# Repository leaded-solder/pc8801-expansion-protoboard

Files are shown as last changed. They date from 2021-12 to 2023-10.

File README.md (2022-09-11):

# NEC PC-8801 expansion protoboard
This board is meant to be a prototyping board for creating expansion cards for the NEC PC-8801 series of Japanese-market personal computers. It is intended to be a substitute for the Sunhayato MCC-151 prototyping board, which is (as far as I know) no longer available for purchase.

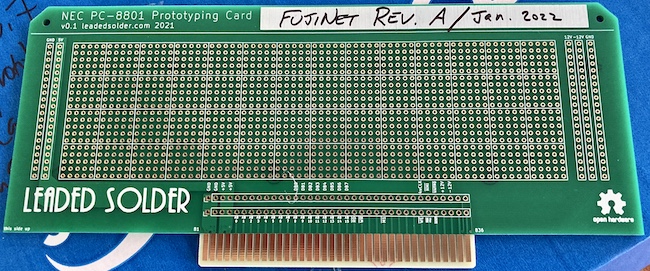
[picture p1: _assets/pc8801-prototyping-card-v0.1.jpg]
An unpopulated v0.1 card with ENIG gold edge fingers


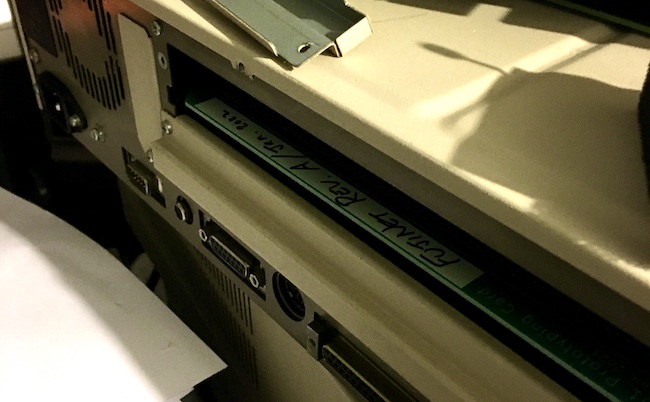
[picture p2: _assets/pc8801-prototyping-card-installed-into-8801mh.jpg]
The card installed into a PC-8801MH


This board was developed as part of a [leaded solder](https://www.leadedsolder.com) web log entry. If it saved you some time or money, [please consider backing the site on Patreon](https://www.patreon.com/leadedsolder).

## Bill of Materials (Optional)
The card itself is enough for most users, but you may wish to add a card ejector in order to make it easier to insert and remove the card while you are prototyping your circuit. The 8801 _really_ gets a death grip on those cards.

I have tested fitment with the common and still-available Bivar CP-26 series ejector, so I suggest buying that. Installing the roll pins for the ejector lever is somewhat challenging for me, so I would appreciate any advice on how to make it faster and more consistent!

## Version History
### v0.3
 - Fixed the problem with the PC-8801 edge footprint where the "B" side pins were on the bottom ("A" side) and the "A" side pins were on the top ("B" side.) As you might expect, this kept things from working!

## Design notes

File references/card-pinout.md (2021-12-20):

# Expansion card pinout for PC-8801
Based on [this page by youkan](http://www.maroon.dti.ne.jp/youkan/pc88/expslot.html)

| Side A (solder side) | I/O | Pin Number | I/O | Side B (part side) |
|---|-----|---|-----|---|
| GND | - | 1 | - | GND |
| GND | - | 2 | - | GND |
| +5V | - | 3 | - | +5V |
| +5V | - | 4 | - | +5V |
| AB0 | O | 5 | - | ~EXTRXRDY |
| AB1 | O | 6 | - | N/C |
| AB2 | O | 7 | I | ~MWAIT[^mwait] |
| AB3 | O | 8 | I | ~INT4 |
| AB4 | O | 9 | I | ~INT3 |
| AB5 | O | 10 | I | ~INT2 |
| AB6 | O | 11 | I | ~FDINT1 |
| AB7 | O | 12 | I | ~FDINT2 |
| AB8 | O | 13 | O | DB0 |
| AB9 | O | 14 | O | DB1 |
| AB10 | O | 15 | O | DB2 |
| AB11 | O | 16 | O | DB3 |
| AB12 | O | 17 | O | DB4 |
| AB13 | O | 18 | O | DB5 |
| AB14 | O | 19 | O | DB6 |
| AB15 | O | 20 | O | DB7 |
| ~RD | O | 21 | O | ~MEMR |
| ~WR | O | 22 | O | HIGH[^high] |
| ~MREQ | O | 23 | O | ~IOW |
| ~IORQ | O | 24 | O | ~IOR |
| ~M1 | O | 25 | O | ~MEMW |
| ~RAS0 | O | 26 | ??  | ~DMATC |
| ~RAS1 | O | 27 | ?? | DMRDY |
| ~RFSH | O | 28 | O | ~DRQ1,2 |
| ~MUX | O | 29 | O | ~DACK1,2 |
| ~WE | O | 30 | O  | 4xCLK[^4clk] |
| ~ROMKILL[^romkill] | I | 31 | I  | ~NMI |
| ~RESET | O | 32 | I  | ~WAITRQ |
| SCLK[^sclk] | O | 33 | -  | +12V |
| CLK[^clk] | O | 34 | -  | -12V |
| V1 | ?? | 35 | ??  | V1 |
| V2 | ?? | 36 | ??  | V2 |

[^high]: Pull-up to +5V
[^romkill]: Prevents computer from accessing built-in ROMs in $0000-7fff
[^mwait]: Adds one wait to the memory access (changes from setting the wait state DIP on the front of the computer)
[^4clk]: 4x CPU clock, AKA 15.9744MHz
[^sclk]: 76.8kHz?
[^clk]: 3.9936MHz

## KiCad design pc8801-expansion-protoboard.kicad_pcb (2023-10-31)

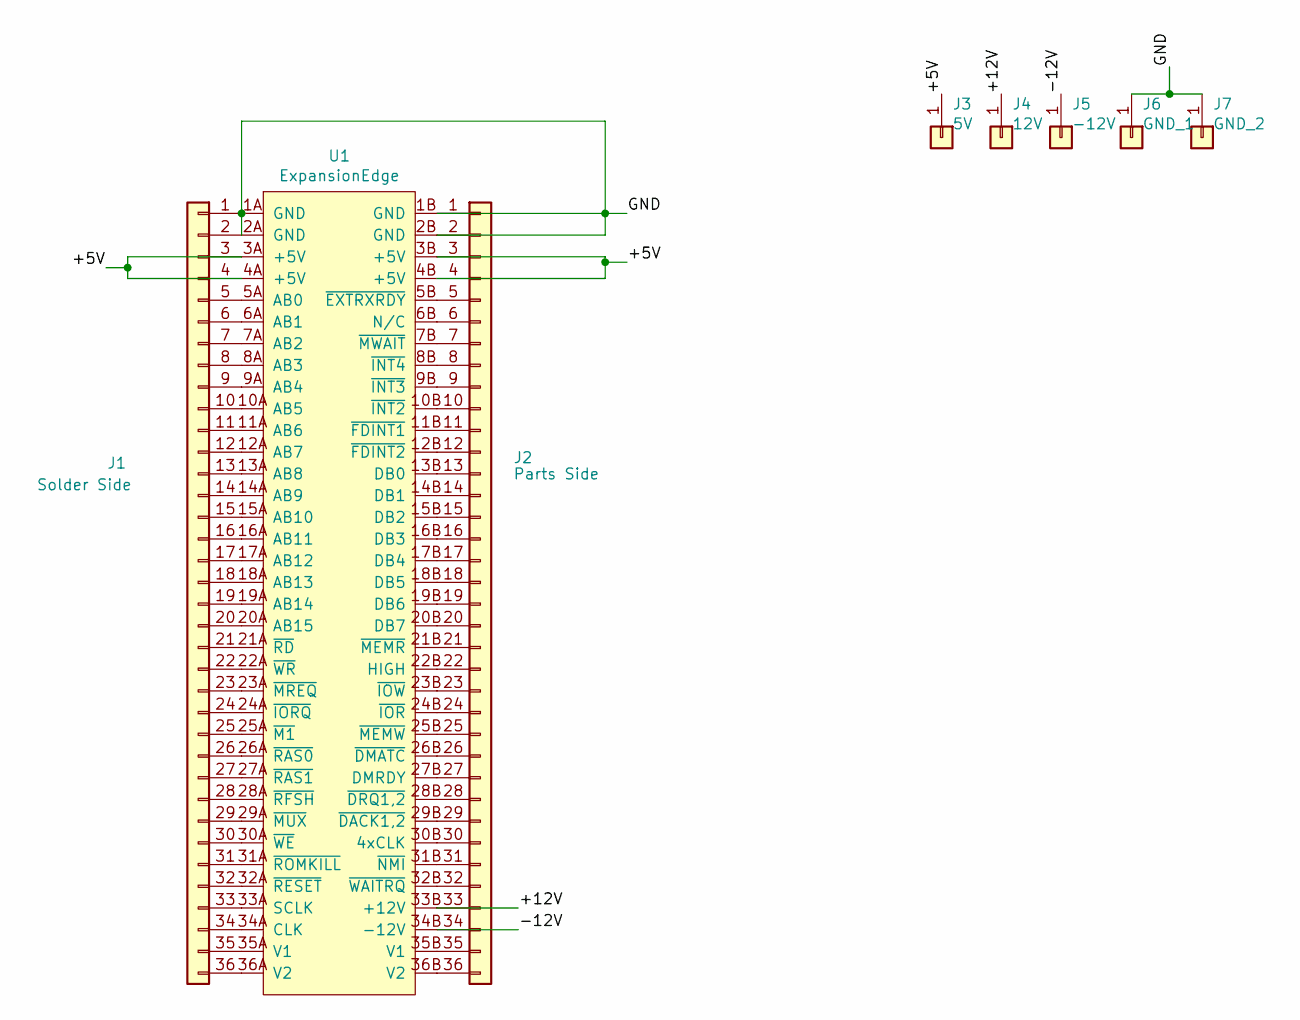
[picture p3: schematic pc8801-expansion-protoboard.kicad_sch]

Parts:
J1: Solder Side; PinHeader_1x36_P2.54mm_Vertical
J2: Parts Side; PinHeader_1x36_P2.54mm_Vertical
J3: 5V; 1x20_PowerBar
J4: 12V; 1x20_PowerBar
J5: -12V; 1x20_PowerBar
J6: GND_1; 1x20_PowerBar
J7: GND_2; 1x20_PowerBar
U1: ExpansionEdge; PC88 Edge

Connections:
/+5V: J1.3, J1.4, J2.3, J2.4, J3.1, U1.3A (+5V), U1.3B (+5V), U1.4A (+5V), U1.4B (+5V)
/+12V: J2.33, J4.1, U1.33B (+12V)
/-12V: J2.34, J5.1, U1.34B (-12V)
/GND: J1.1, J1.2, J2.1, J2.2, J6.1, J7.1, U1.1A (GND), U1.1B (GND), U1.2A (GND), U1.2B (GND)
unnamed: J1.5, U1.5A (AB0)
unnamed: J1.6, U1.6A (AB1)
unnamed: J1.7, U1.7A (AB2)
unnamed: J1.8, U1.8A (AB3)
unnamed: J1.9, U1.9A (AB4)
unnamed: J1.10, U1.10A (AB5)
unnamed: J1.11, U1.11A (AB6)
unnamed: J1.12, U1.12A (AB7)
unnamed: J1.13, U1.13A (AB8)
unnamed: J1.14, U1.14A (AB9)
unnamed: J1.15, U1.15A (AB10)
unnamed: J1.16, U1.16A (AB11)
unnamed: J1.17, U1.17A (AB12)
unnamed: J1.18, U1.18A (AB13)
unnamed: J1.19, U1.19A (AB14)
unnamed: J1.20, U1.20A (AB15)
unnamed: J1.21, U1.21A (~RD)
unnamed: J1.22, U1.22A (~WR)
unnamed: J1.23, U1.23A (~MREQ)
unnamed: J1.24, U1.24A (~IORQ)
unnamed: J1.25, U1.25A (~M1)
unnamed: J1.26, U1.26A (~RAS0)
unnamed: J1.27, U1.27A (~RAS1)
unnamed: J1.28, U1.28A (~RFSH)
unnamed: J1.29, U1.29A (~MUX)
unnamed: J1.30, U1.30A (~WE)
unnamed: J1.31, U1.31A (~ROMKILL)
unnamed: J1.32, U1.32A (~RESET)
unnamed: J1.33, U1.33A (SCLK)
unnamed: J1.34, U1.34A (CLK)
unnamed: J1.35, U1.35A (V1)
unnamed: J1.36, U1.36A (V2)
unnamed: J2.5, U1.5B (~EXTRXRDY)
unnamed: J2.6, U1.6B (N/C)
unnamed: J2.7, U1.7B (~MWAIT)
unnamed: J2.8, U1.8B (~INT4)
unnamed: J2.9, U1.9B (~INT3)
unnamed: J2.10, U1.10B (~INT2)
unnamed: J2.11, U1.11B (~FDINT1)
unnamed: J2.12, U1.12B (~FDINT2)
unnamed: J2.13, U1.13B (DB0)
unnamed: J2.14, U1.14B (DB1)
unnamed: J2.15, U1.15B (DB2)
unnamed: J2.16, U1.16B (DB3)
unnamed: J2.17, U1.17B (DB4)
unnamed: J2.18, U1.18B (DB5)
unnamed: J2.19, U1.19B (DB6)
unnamed: J2.20, U1.20B (DB7)
unnamed: J2.21, U1.21B (~MEMR)
unnamed: J2.22, U1.22B (HIGH)
unnamed: J2.23, U1.23B (~IOW)
unnamed: J2.24, U1.24B (~IOR)
unnamed: J2.25, U1.25B (~MEMW)
unnamed: J2.26, U1.26B (~DMATC)
unnamed: J2.27, U1.27B (DMRDY)
unnamed: J2.28, U1.28B (~DRQ1,2)
unnamed: J2.29, U1.29B (~DACK1,2)
unnamed: J2.30, U1.30B (4xCLK)
unnamed: J2.31, U1.31B (~NMI)
unnamed: J2.32, U1.32B (~WAITRQ)
unnamed: J2.35, U1.35B (V1)
unnamed: J2.36, U1.36B (V2)

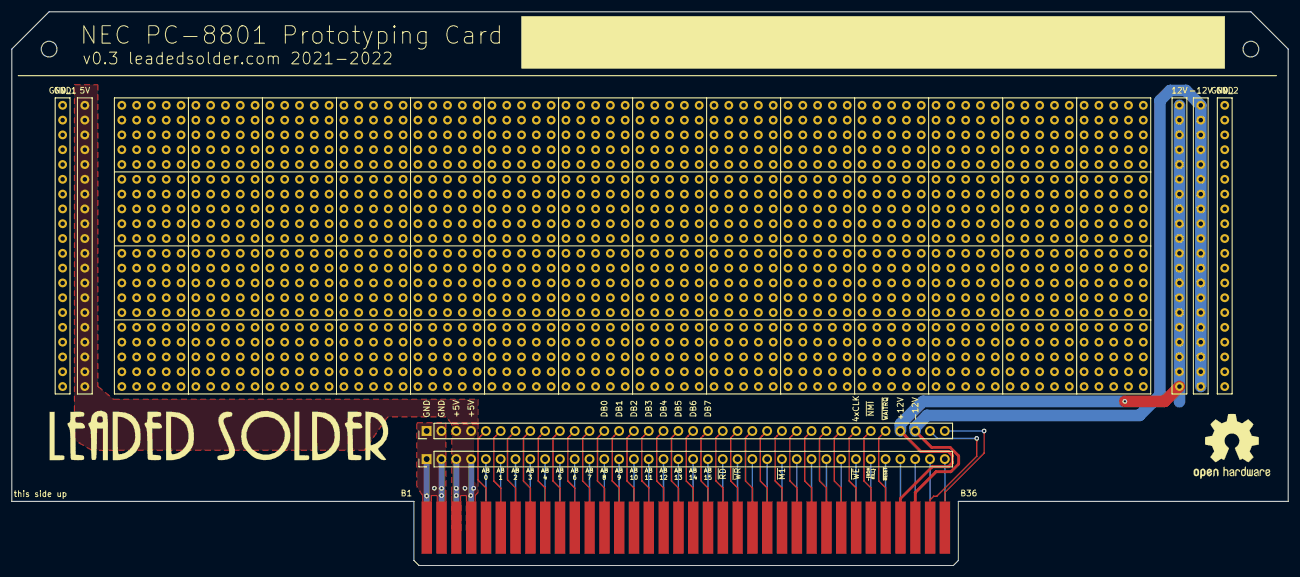
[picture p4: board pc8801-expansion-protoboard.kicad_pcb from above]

Board: 2 copper layers, 219.0 x 95.0 mm, 8 parts (0 on the bottom side), 66 nets.

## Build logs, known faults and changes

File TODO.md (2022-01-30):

 - [x] Figure out the edge connector tooth width and depth
 - [x] Figure out more exact dimensions (printout test-fit) of board edge
 - [x] Make an edge connector footprint
 - [x] Make a "power bar" footprint for 5, 12, -12, GND
 - [x] Copy net assignments to all of the power bars
 - [x] Make a "proto area" footprint
 - [x] Should the edge be chamfered?
 - [ ] Look at options for backplane covers
 - [x] Look at the thumb-release lever footprints, see if the screw holes can be tweaked (m3, 5mm ring)
 - [x] print, cut out, and test an example
 - [x] fix the alignment based on the SB-II measurements
 - [x] choose an ejector - Bivar CP-26 seems fine
 - [x] adjust PCB for ejector holes
 - [x] send away for first revision...
 - [x] test fit first revision
 - [x] create README with BOM

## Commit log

2021-12-20 Symbol and schematic
    [pc8801-expansion-protoboard.kicad_pcb, pc8801-expansion-protoboard.sch]
2021-12-20 Tying power nets together
    [pc8801-expansion-protoboard.sch]
2021-12-20 Some progress
    [pc8801-expansion-protoboard.kicad_pcb, pc8801-expansion-protoboard.sch]
2021-12-20 Minor silk prep
    [pc8801-expansion-protoboard.kicad_pcb]
2021-12-20 Power bars
    [pc8801-expansion-protoboard.kicad_pcb, pc8801-expansion-protoboard.sch]
2021-12-20 Power rails, of a sort
    [pc8801-expansion-protoboard.kicad_pcb]
2021-12-25 Here goes nothing
    [pc8801-expansion-protoboard.kicad_pcb, pc8801-expansion-protoboard.sch]
2021-12-26 need to fix edge cut
    [pc8801-expansion-protoboard.kicad_pcb]
2021-12-30 Edge brought over to get closer to SB-II clone
    [pc8801-expansion-protoboard.kicad_pcb]
2022-01-11 ejector holes
    [pc8801-expansion-protoboard.kicad_pcb]
2022-01-11 little baby edge chamfer
    [pc8801-expansion-protoboard.kicad_pcb]
2022-01-11 Unnecessary logo
    [pc8801-expansion-protoboard.kicad_pcb]
2022-01-17 Bump copyright date
    [pc8801-expansion-protoboard.kicad_pcb]
2022-01-31 Ejector notes
    [pc8801-expansion-protoboard.kicad_pcb]
2022-02-01 Move pours around to help avoid rubbing on the ejectors
    [pc8801-expansion-protoboard.kicad_pcb]
2022-09-11 Fix flipped edge
    [pc8801-expansion-protoboard.kicad_pcb]
2023-10-31 Fix symbol problem
    [pc8801-expansion-protoboard.kicad_sch]
2023-10-31 Reflow pours
    [pc8801-expansion-protoboard.kicad_pcb]
